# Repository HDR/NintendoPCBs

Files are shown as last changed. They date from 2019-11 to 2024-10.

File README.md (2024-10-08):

# [Make sure you read the License before downloading anything!](https://github.com/HDR/NintendoPCBs/blob/master/LICENSE)

# Please note that these boards can only be used to fix broken games, they can not be used for piracy/bootleg games

**All boards should be ordered in 0.8mm thickness with ENIG, Do not order in 1.6mm thickness or HASL!**

**AGB-E02-20:**

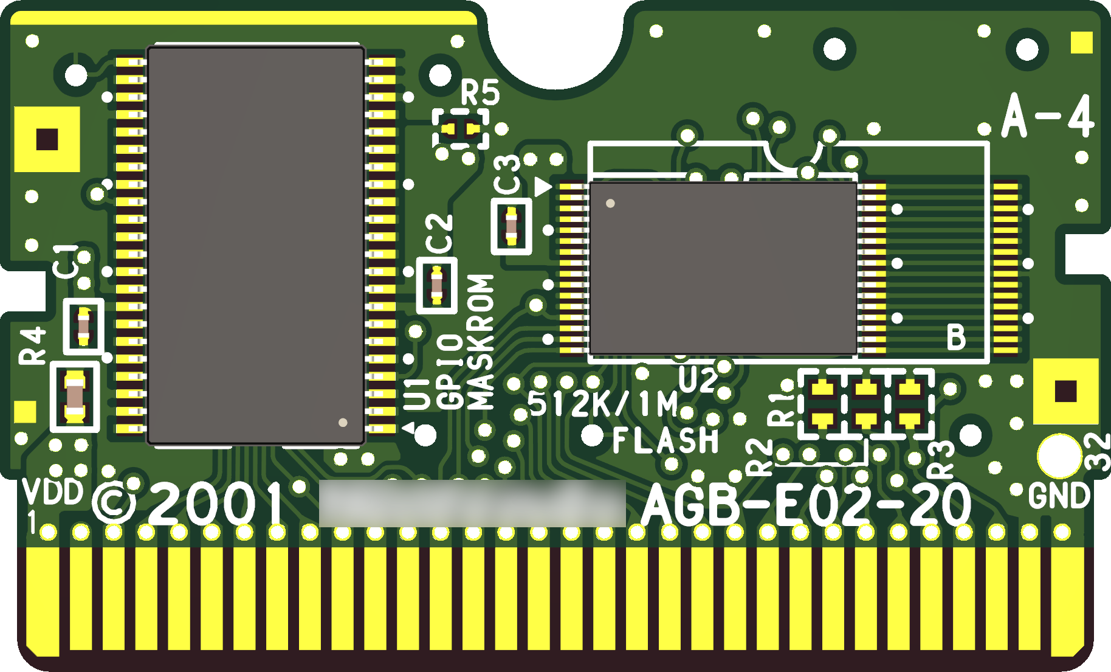
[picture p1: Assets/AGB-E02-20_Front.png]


**AGB-E05-01:**

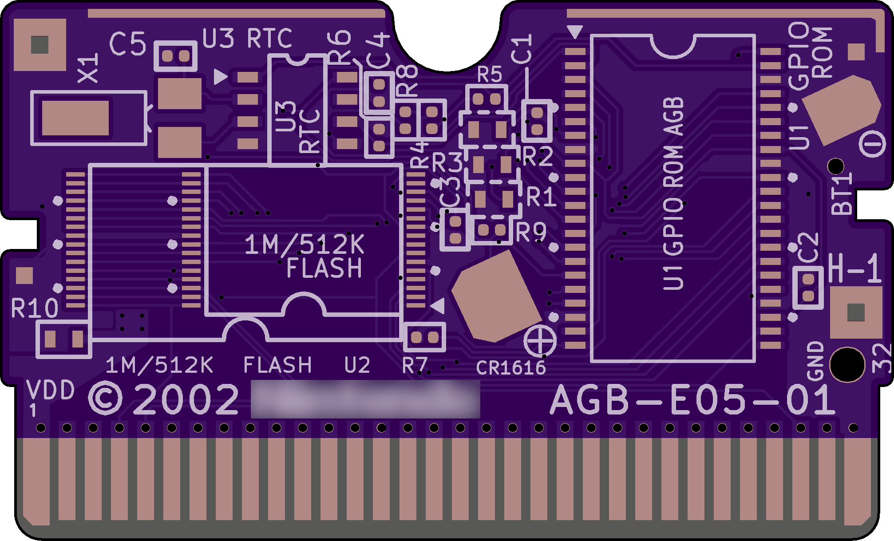
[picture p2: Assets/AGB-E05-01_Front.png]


**DMG-KFDN-01:**

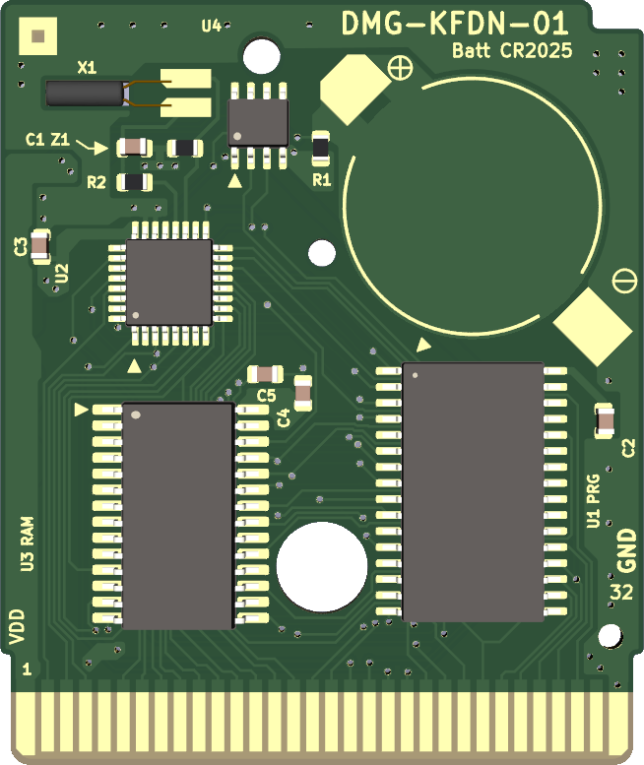
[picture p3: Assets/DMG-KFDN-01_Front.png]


See the [Nintendo Board Scans](https://github.com/HDR/Nintendo_Board_Scans) for more.

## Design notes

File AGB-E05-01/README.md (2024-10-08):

# AGB-E05-01

Intended as a replacement for Games like Emerald

## BOM
| **Designator** | **Part** |
|:---:|:---:|
| C1,C2,C3,C4 | 100nF 0402 |
| C5 | 4pF or 10pF 0402 (depends on the board) |
| R1,R2,R3 | Unpopulated |
| R4,R5,R9 | 10K 0402 |
| R6,R7 | 100K 0402 |
| R8 | 1K 0402 |
| R10 | 2K Resistor 0603 or 1uF Capacitor 0603 (depends on the board) |

### Images


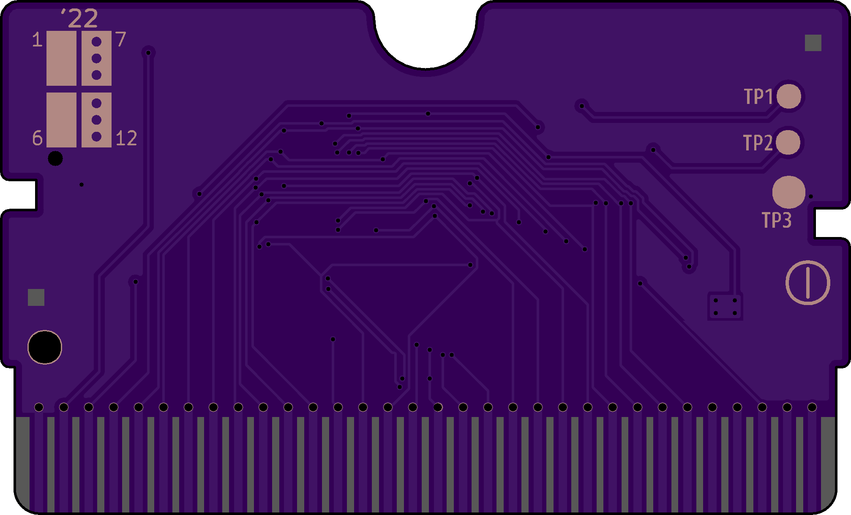
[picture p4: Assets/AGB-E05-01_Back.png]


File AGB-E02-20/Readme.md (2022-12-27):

# AGB-E02-20

Intended as a replacement for Games like Fire Red & Leaf Green

## BOM
| **Designator** | **Part** |
|---|---|
| U1 | MX23L12806-12C (Must to be harvested) |
| U2 | LE26FV10N1TS (Must to be harvested) |
| R1,R2,R3 | Unpopulated |
| R4 | 2.2uF 0603 |
| R5 | Unpopulated |

### Images


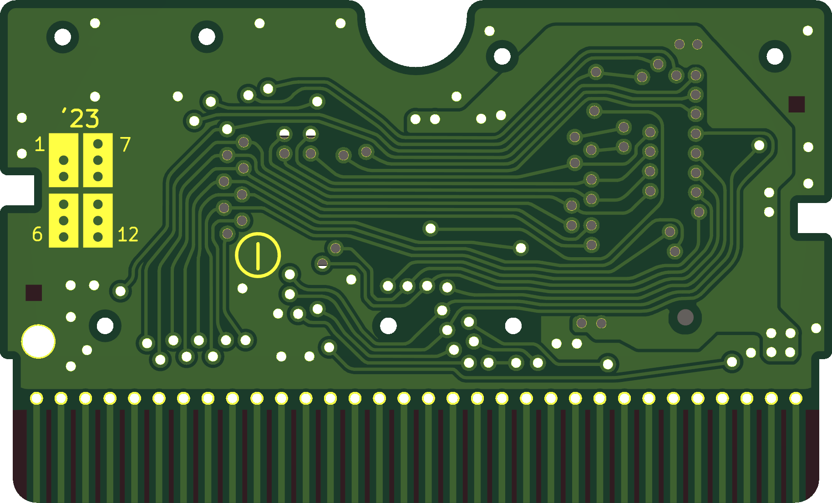
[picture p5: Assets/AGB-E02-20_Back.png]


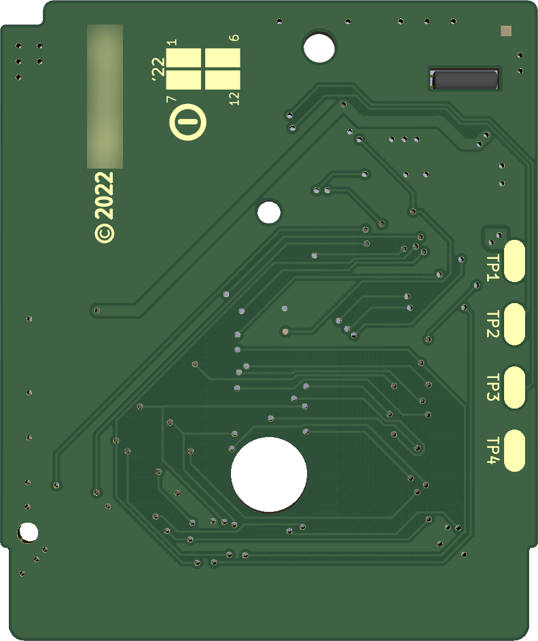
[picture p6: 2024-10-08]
Assets/DMG-KFDN-01_Back.png

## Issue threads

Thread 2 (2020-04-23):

Assembled AGB-E02-20 Board

emuman100, 2020-04-23:
I had the board made with a thickness of .8mm at OSH Park. For the LE26FV10NITS-10 save flash, the pad spacing is just large enough and it had to be very carefully aligned and was a bit difficult to flow solder since the pads were not pretinned, but ENIG plated.

I soldered the save flash, mask ROM, and capacitors of Super Mario Advance 4 and it did not boot. The mask ROM is AX4E-0. Have you tested this design?

HDR, 2020-04-23:
Yep, works as it should.

emuman100, 2020-04-23:
Ok, maybe something happened to this masked ROM. It was a working cartridge, then just stopped working. Usually the masked ROMs are pretty reliable. I'll just have to try with another donor cartridge. Picture attached.
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

emuman100, 2020-04-23:
It won't even read in my insidegadgets programmer. I believe it is the mask ROM.

Closed 2020-04-23.

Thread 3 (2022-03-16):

how to build Dookie ?

hpx1984, 2022-03-16:
Hi Sir HDR

The Ique dookie project is the clones of ique card,right?

i had download Dookie Gerber and Sch but can't open it by CAM350 and Protel99, what PC tool can open it?

the process how to clones ique card in my understand,am i right?
1.dump original NAND from original ique card
2.build Dookie PCBA
3. upload original NAND file to Dookie PCBA

hpx1984, 2022-03-16:
CAM350 can open AGB-E05-01 but Dookie gerber showed as below
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

hpx1984, 2022-03-17:
hi HDR
thanks your replayed

i used CAM350 for open DOOKIE gerber always got error as this or just sew the "Drl" layer
i thinking about for rebuild a ique card for lager memory for install all 14 ique player games in one ique card
and i think DOOKIE project is what i want when i saw this project , i like to try to build it
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

HDR, 2022-03-17:
Your software is broken, you need to upload the gerber to a fab.

hpx1984, 2022-04-02:
Dear MrHDR

i got ique memory card DOOKIE PCB now
and i try for soldering a nand chip and cap on it but i can't programmed nand bin file on it by used ique player hot swap memory card and use ique_diag tool
is it mean need nand programmer for read nand file from original memory card's nand chip then programming nand file to new nand chip by programmer?

sorry for trouble you and many thanks your kindly help

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

HDR, 2022-04-02:
Not sure, i haven't tried using them myself, i just cloned the board.

hpx1984, 2022-04-02:
okay ,let me try myself , many thanks your replied Mr HDR
thank you very much

Closed 2022-03-16.

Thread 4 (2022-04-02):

DMG-KFDN-01 - C4, C5 missing connection to ground.

mkarr, 2022-04-02:
Hi,

It appears that in both the schematic and pcb for the DMG-KFDN-01 project, C4 and C5 are connected together, but that connecting net is not connected to ground.

Looking over the PCB pictures here:

https://gbhwdb.gekkio.fi/cartridges/DMG-APAU-0/mattcurrie-1.html

It appears that the ground connection is there, similar MBC3 boards appear to have the same connections for the SRAM.

Thanks,

Mike

HDR, 2022-04-03:
Whoops, when i originally made some of those i was kind of a newbie when it came to pcb's, i just pushed d1a9a5f which should fix this.

Closed 2022-04-03.

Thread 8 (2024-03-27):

Question - Is there a reason some pads are many pads connected to each other?

sabogalc, 2024-03-27:
In this example, I am looking at the pads of `U1` on the `AGB-E02-20` PCB. I am wondering if there is any particular reason that the pads are all three pads strung together instead of one pad. I am looking to submit a PR that corrects this, but before I do so I wanted to check if this was the intended design.
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

HDR, 2024-03-27:
This is intentional, please look at an original board or the 3d view.

Closed 2024-03-27.

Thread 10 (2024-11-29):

AGB-E02-20 missing materials for C1-C3

andreevgy, 2024-11-29:
Hello!

I am kinda new to hobby electronics and trying to fix AGB-E02-20 that I bought secondhand. I successfully transferred chips and elements that I had on previous board, but from photos online it seems like I have С1-С3 missing.

In the BOM of AGB-E02-20 there is no C1-C3. Maybe they shouldn't be here and I just screwed my cartridge, but I see all other boards mention it. Will appreciate any help and thank you for the designs!

HDR, 2024-11-29:
C1-C3 are 0.1uF (100nF) 0402 capacitors, i've updated the BOM to reflect this

Closed 2024-11-29.

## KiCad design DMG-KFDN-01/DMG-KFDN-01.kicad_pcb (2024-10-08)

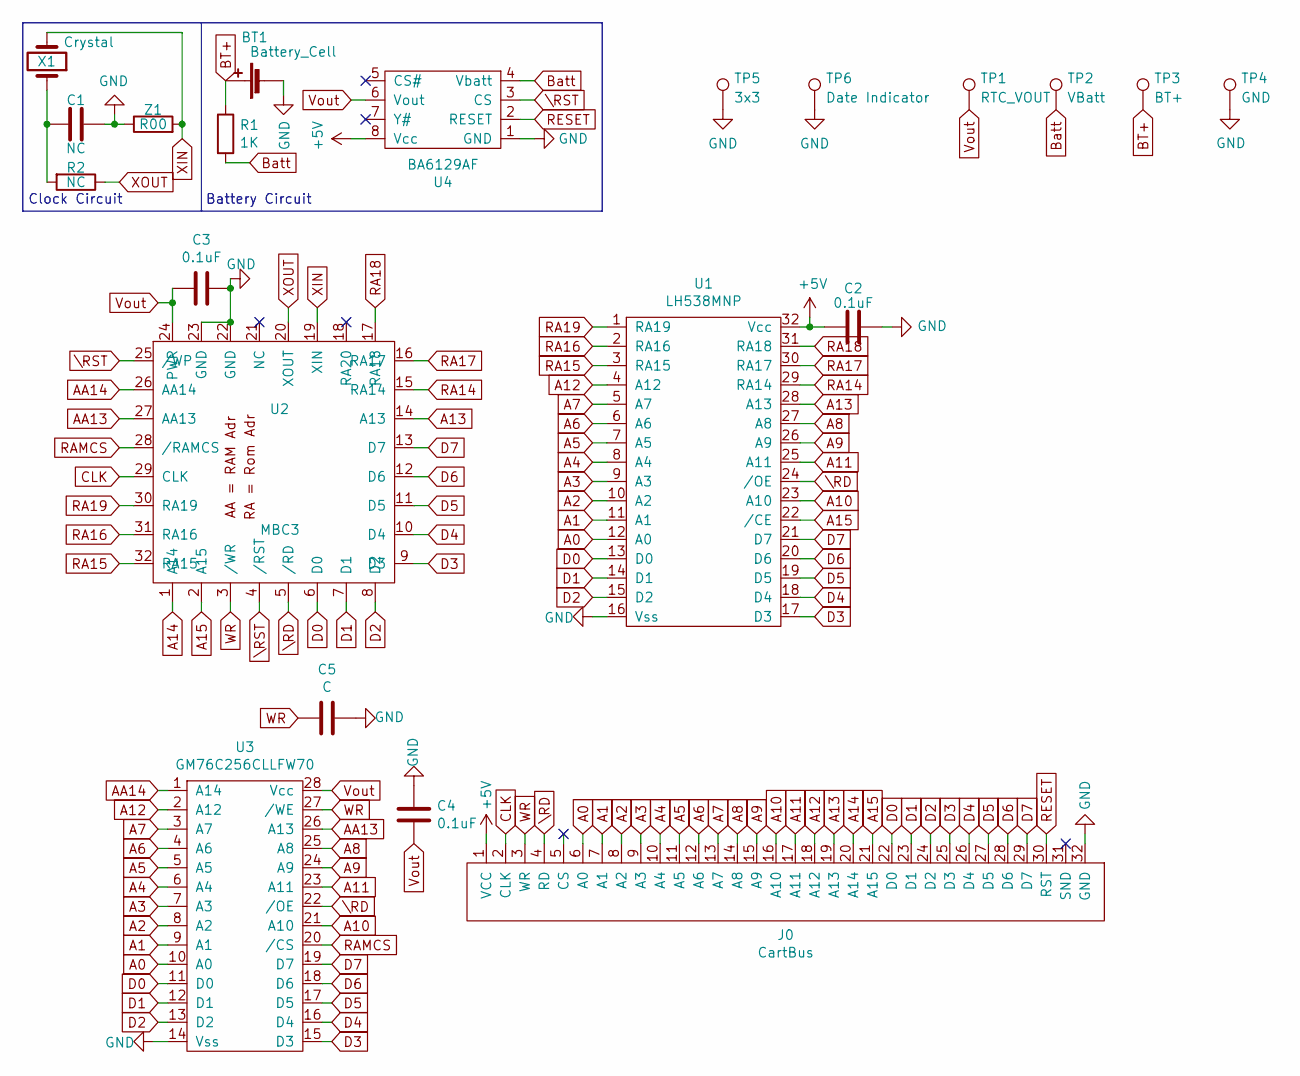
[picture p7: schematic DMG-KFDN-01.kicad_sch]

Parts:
BT1: Battery_Cell; CR2025_Tabbed
C1: NC; C_0805_2012Metric
C2, C3, C4: 0.1uF; C_0805_2012Metric
C5: C; C_0805_2012Metric
J0: CartBus; GB_Cartridge_Front_Only
R1: 1K; R_0805_2012Metric
R2: NC; R_0805_2012Metric
TP1: RTC_VOUT; GameBoy_Testpoint
TP2: VBatt; GameBoy_Testpoint
TP3: BT+; GameBoy_Testpoint
TP4: GND; GameBoy_Testpoint
TP5: 3x3; 3x3mm_Pad
TP6: Date Indicator; 12 December
U1: LH538MNP; SSOP-32_11.305x20.495mm_P1.27mm
U2: MBC3; LQFP-32_7x7mm_P0.8mm
U3: GM76C256CLLFW70; SOIC-28W_7.5x17.9mm_P1.27mm
U4: BA6129AF; SOIC-8_3.9x4.9mm_P1.27mm
X1: Crystal; Resonator_SMD_muRata_CDSCB-2pin_4.5x2.0mm_HandSoldering
Z1: R00; R_0805_2012Metric

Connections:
+5V: C2.1, J0.1 (VCC), U1.32 (Vcc), U4.8 (Vcc)
A0: J0.6 (A0), U1.12 (A0), U3.10 (A0)
A1: J0.7 (A1), U1.11 (A1), U3.9 (A1)
A2: J0.8 (A2), U1.10 (A2), U3.8 (A2)
A3: J0.9 (A3), U1.9 (A3), U3.7 (A3)
A4: J0.10 (A4), U1.8 (A4), U3.6 (A4)
A5: J0.11 (A5), U1.7 (A5), U3.5 (A5)
A6: J0.12 (A6), U1.6 (A6), U3.4 (A6)
A7: J0.13 (A7), U1.5 (A7), U3.3 (A7)
A8: J0.14 (A8), U1.27 (A8), U3.25 (A8)
A9: J0.15 (A9), U1.26 (A9), U3.24 (A9)
A10: J0.16 (A10), U1.23 (A10), U3.21 (A10)
A11: J0.17 (A11), U1.25 (A11), U3.23 (A11)
A12: J0.18 (A12), U1.4 (A12), U3.2 (A12)
A13: J0.19 (A13), U1.28 (A13), U2.14 (A13)
A14: J0.20 (A14), U2.1 (A14)
A15: J0.21 (A15), U1.22 (/CE), U2.2 (A15)
AA13: U2.27 (AA13), U3.26 (A13)
AA14: U2.26 (AA14), U3.1 (A14)
BT+: BT1.1 (+), R1.1, TP3.1; also elsewhere on the board
Batt: R1.2, TP2.1, U4.4 (Vbatt)
CLK: J0.2 (CLK~), U2.29 (CLK)
D0: J0.22 (D0), U1.13 (D0), U2.6 (D0), U3.11 (D0)
D1: J0.23 (D1), U1.14 (D1), U2.7 (D1), U3.12 (D1)
D2: J0.24 (D2), U1.15 (D2), U2.8 (D2), U3.13 (D2)
D3: J0.25 (D3), U1.17 (D3), U2.9 (D3), U3.15 (D3)
D4: J0.26 (D4), U1.18 (D4), U2.10 (D4), U3.16 (D4)
D5: J0.27 (D5), U1.19 (D5), U2.11 (D5), U3.17 (D5)
D6: J0.28 (D6), U1.20 (D6), U2.12 (D6), U3.18 (D6)
D7: J0.29 (D7), U1.21 (D7), U2.13 (D7), U3.19 (D7)
GND: BT1.2 (-), C1.2, C2.2, C3.2, C4.1, C5.1, J0.32 (GND), TP4.1, TP5.1, TP6.1, U1.16 (Vss), U2.22 (GND), U2.23 (GND), U3.14 (Vss), U4.1 (GND), Z1.1; also elsewhere on the board
unnamed: C1.1, R2.2, X1.1
RA14: U1.29 (RA14), U2.15 (RA14)
RA15: U1.3 (RA15), U2.32 (RA15)
RA16: U1.2 (RA16), U2.31 (RA16)
RA17: U1.30 (RA17), U2.16 (RA17)
RA18: U1.31 (RA18), U2.17 (RA18)
RA19: U1.1 (RA19), U2.30 (RA19)
RAMCS: U2.28 (/RAMCS), U3.20 (/CS)
RESET: J0.30 (RST), U4.2 (RESET)
Vout: C3.1, C4.2, TP1.1, U2.24 (PWR), U3.28 (Vcc), U4.6 (Vout)
WR: C5.2, J0.3 (WR), U2.3 (/WR), U3.27 (/WE)
XIN: U2.19 (XIN), X1.2, Z1.2
XOUT: R2.1, U2.20 (XOUT)
\RD: J0.4 (RD), U1.24 (/OE), U2.5 (/RD), U3.22 (/OE)
\RST: U2.4 (/RST), U2.25 (/WP), U4.3 (CS)

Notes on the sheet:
Battery Circuit
Clock Circuit

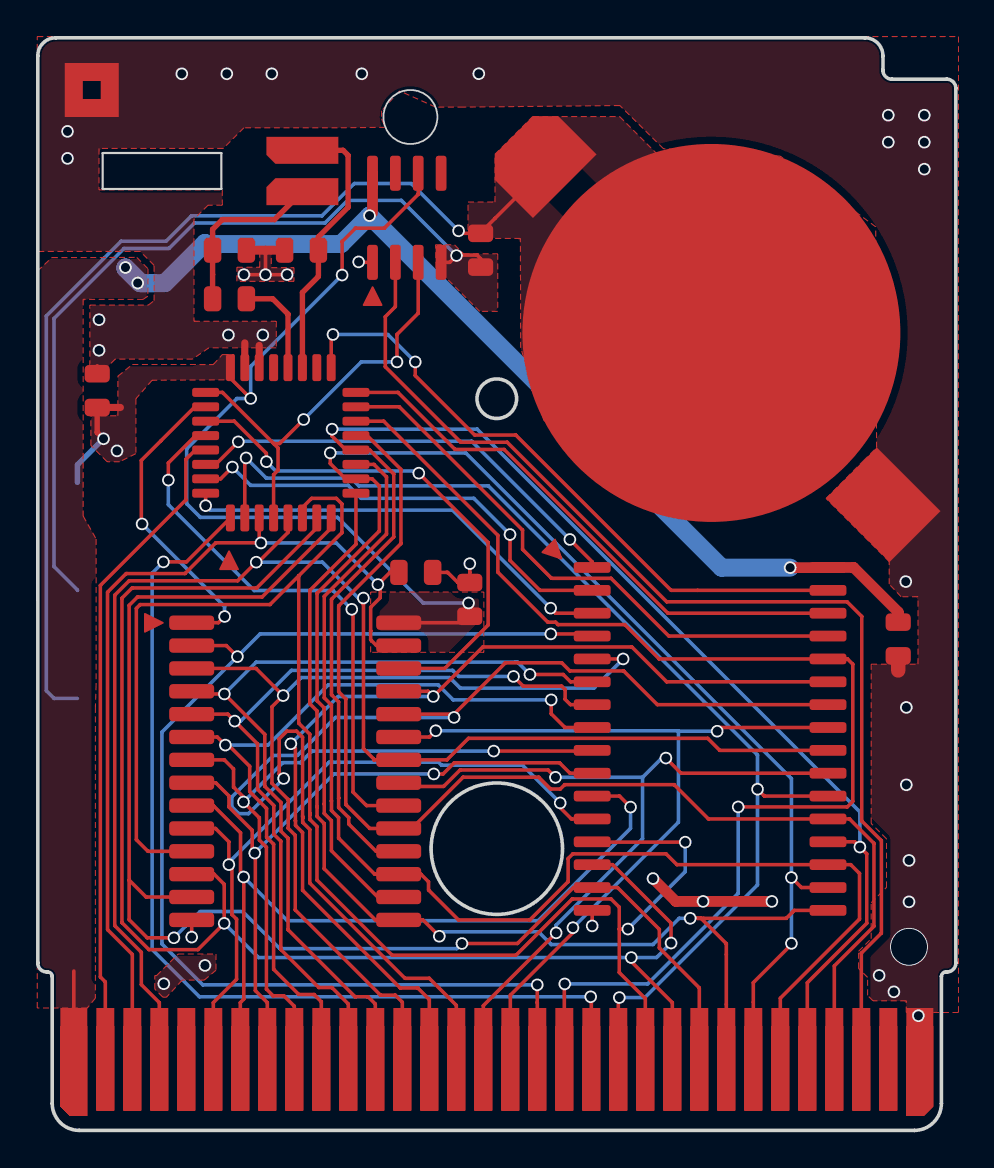
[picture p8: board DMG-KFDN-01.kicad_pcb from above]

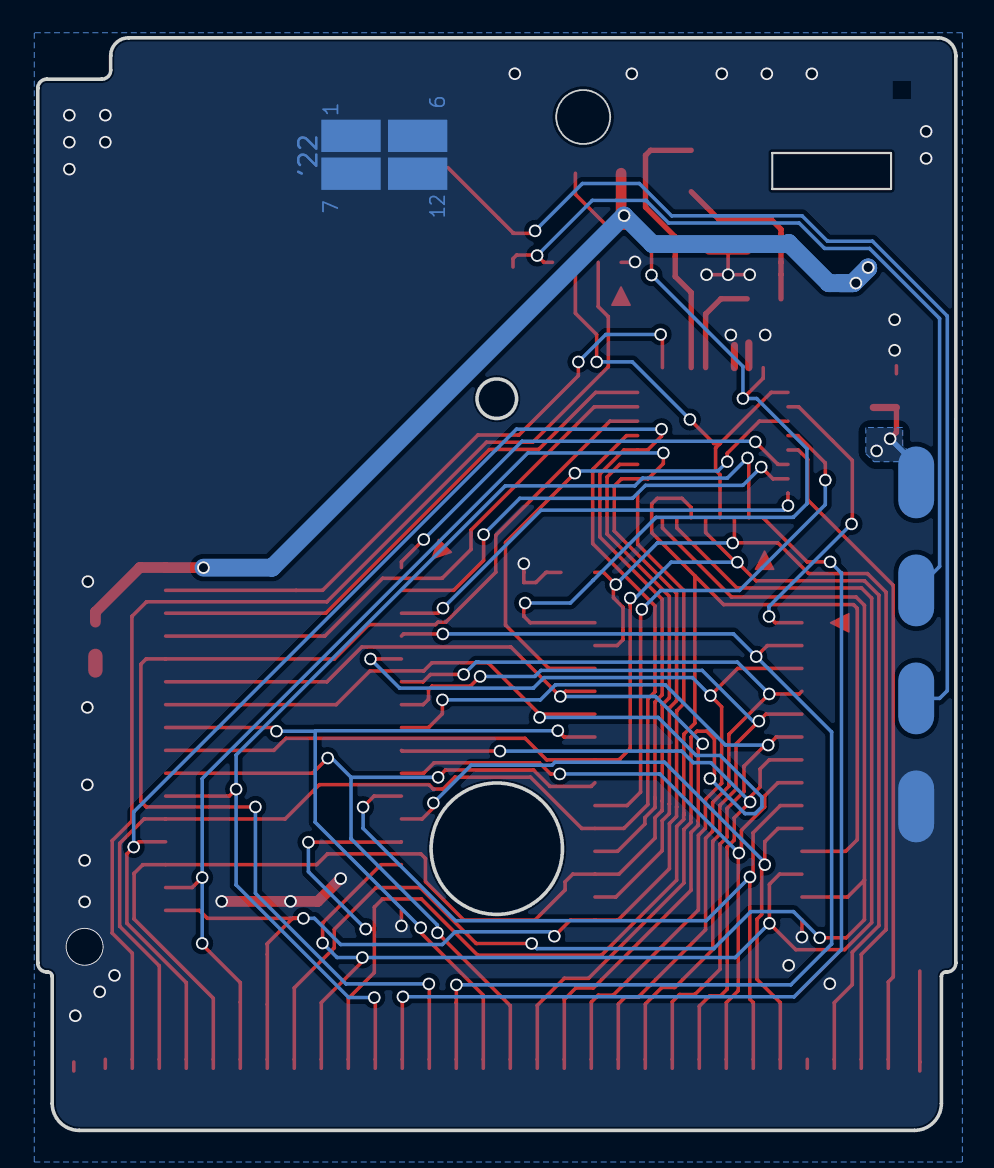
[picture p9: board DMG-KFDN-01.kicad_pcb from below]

Board: 2 copper layers, 51.0 x 60.7 mm, 21 parts (5 on the bottom side), 46 nets.

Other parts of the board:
Batt CR2025: Battery_Cell; CR2025_Tabbed

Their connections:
BT+: Batt CR2025.1 (+); also elsewhere on the board
GND: Batt CR2025.2 (-); also elsewhere on the board

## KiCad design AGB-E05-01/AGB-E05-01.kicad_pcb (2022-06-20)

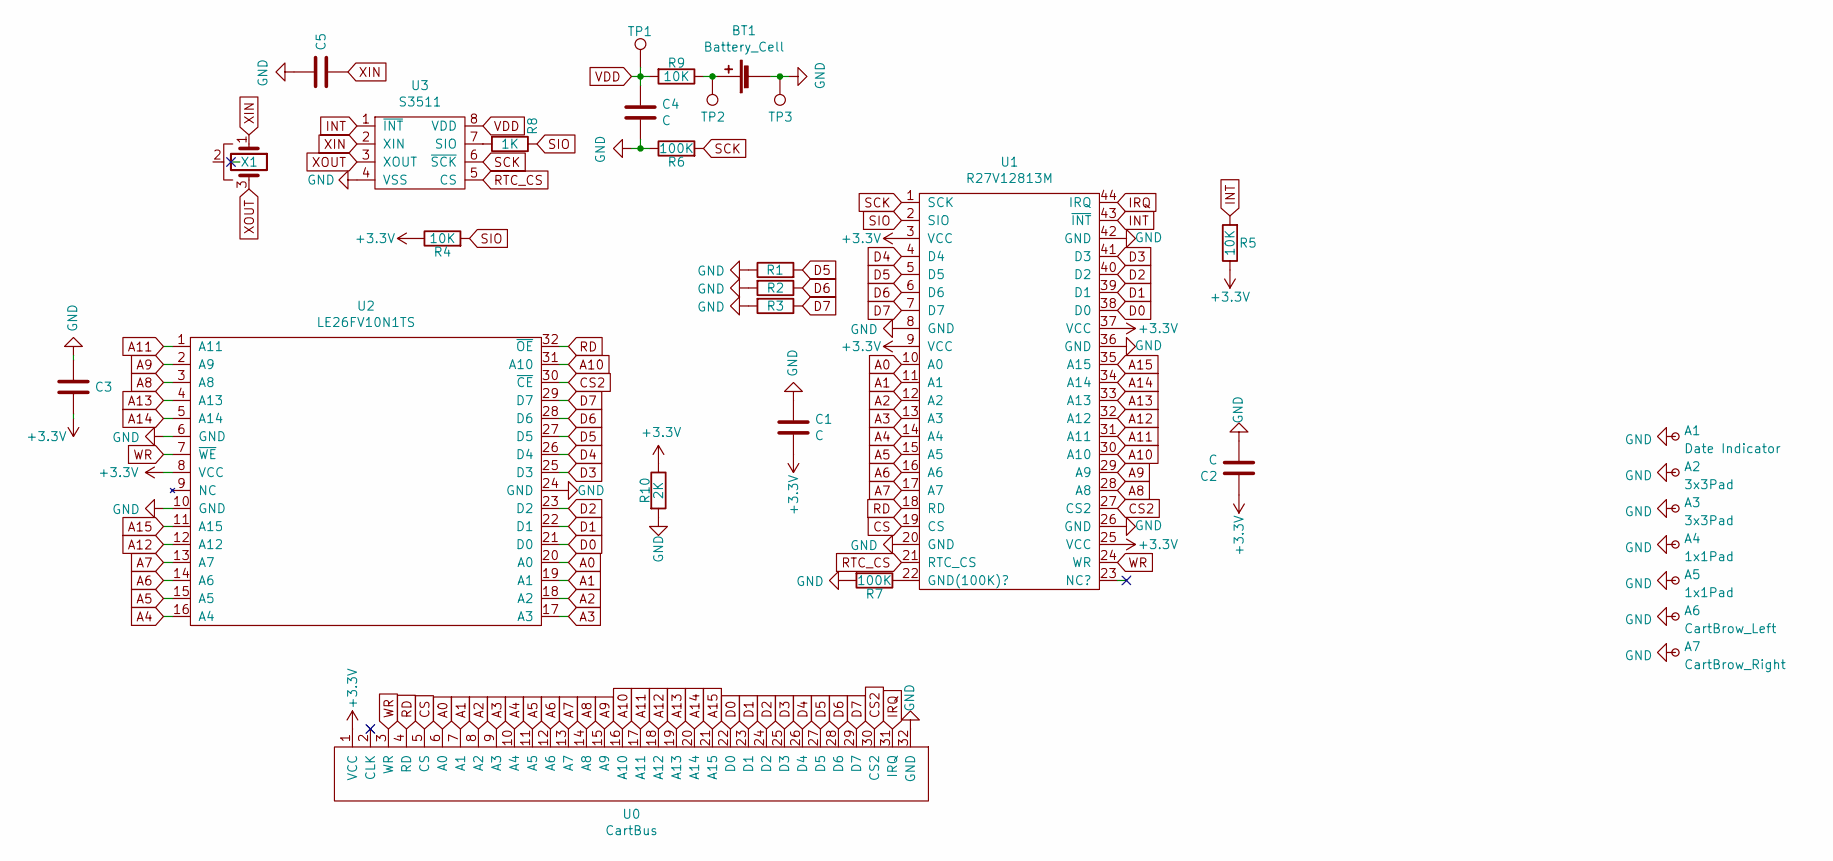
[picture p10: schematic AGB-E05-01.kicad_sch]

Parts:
A1: Date Indicator; 05 May
A2, A3: 3x3Pad; 3x3mm_Pad
A4, A5: 1x1Pad; 1x1mm_Pad
A6: CartBrow_Left; AGB-Cartbrow_Left
A7: CartBrow_Right; AGB-Cartbrow_Right
BT1: Battery_Cell; AGB-CR1616
C1, C2, C3, C4, C5: C; AGB-C_0402
R1, R2, R3: NC; AGB-R-0603_OPT
R4, R5, R9: 10K; AGB-R_0402
R6, R7: 100K; AGB-R_0402
R8: 1K; AGB-R_0402
R10: 2K; AGB-R-0603
TP1, TP2: TestPoint; AGB-Testpoint
TP3: TestPoint; AGB-Testpoint_Ground
U0: CartBus; AGB_Cartridge
U1: R27V12813M; AGB-TSOP-II-44_10.16x18.41mm_P0.8mm
U2: LE26FV10N1TS; AGB-TSOP-I-32
U3: S3511; AGB-SSOP8
X1: Crystal_GND2; AGB-Crystal

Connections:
+3V3: C1.1, C2.2, C3.1, R4.1, R5.1, R10.1, U0.1 (VCC), U1.3 (VCC), U1.9 (VCC), U1.25 (VCC), U1.37 (VCC), U2.8 (VCC)
A0: U0.6 (A0), U1.10 (A0), U2.20 (A0)
A1: U0.7 (A1), U1.11 (A1), U2.19 (A1)
A2: U0.8 (A2), U1.12 (A2), U2.18 (A2)
A3: U0.9 (A3), U1.13 (A3), U2.17 (A3)
A4: U0.10 (A4), U1.14 (A4), U2.16 (A4)
A5: U0.11 (A5), U1.15 (A5), U2.15 (A5)
A6: U0.12 (A6), U1.16 (A6), U2.14 (A6)
A7: U0.13 (A7), U1.17 (A7), U2.13 (A7)
A8: U0.14 (A8), U1.28 (A8), U2.3 (A8)
A9: U0.15 (A9), U1.29 (A9), U2.2 (A9)
A10: U0.16 (A10), U1.30 (A10), U2.31 (A10)
A11: U0.17 (A11), U1.31 (A11), U2.1 (A11)
A12: U0.18 (A12), U1.32 (A12), U2.12 (A12)
A13: U0.19 (A13), U1.33 (A13), U2.4 (A13)
A14: U0.20 (A14), U1.34 (A14), U2.5 (A14)
A15: U0.21 (A15), U1.35 (A15), U2.11 (A15)
CS: U0.5 (CS), U1.19 (CS)
CS2: U0.30 (CS2), U1.27 (CS2), U2.30 (~CE)
D0: U0.22 (D0), U1.38 (D0), U2.21 (D0)
D1: U0.23 (D1), U1.39 (D1), U2.22 (D1)
D2: U0.24 (D2), U1.40 (D2), U2.23 (D2)
D3: U0.25 (D3), U1.41 (D3), U2.25 (D3)
D4: U0.26 (D4), U1.4 (D4), U2.26 (D4)
D5: R1.2, U0.27 (D5), U1.5 (D5), U2.27 (D5)
D6: R2.1, U0.28 (D6), U1.6 (D6), U2.28 (D6)
D7: R3.1, U0.29 (D7), U1.7 (D7), U2.29 (D7)
GND: A1.1, A2.1, A3.1, A4.1, A5.1, A6.1, A7.1, BT1.2 (-), C1.2, C2.1, C3.2, C4.1, C5.1, R1.1, R2.2, R3.2, R6.1, R7.2, R10.2, TP3.1, U0.32 (GND), U1.8 (GND), U1.20 (GND), U1.26 (GND), U1.36 (GND), U1.42 (GND), U2.6 (GND), U2.10 (GND), U2.24 (GND), U3.4 (VSS); also elsewhere on the board
INT: R5.2, U1.43 (~INT), U3.1 (~INT)
IRQ: U0.31 (IRQ), U1.44 (IRQ)
unnamed: BT1.1 (+), R9.1, TP2.1
unnamed: R7.1, U1.22 (GND(100K)?)
unnamed: R8.2, U3.7 (SIO)
RD: U0.4 (RD), U1.18 (RD), U2.32 (~OE)
RTC_CS: U1.21 (RTC_CS), U3.5 (CS)
SCK: R6.2, U1.1 (SCK), U3.6 (~SCK)
SIO: R4.2, R8.1, U1.2 (SIO)
VDD: C4.2, R9.2, TP1.1, U3.8 (VDD)
WR: U0.3 (WR), U1.24 (WR), U2.7 (~WE)
XIN: C5.2, U3.2 (XIN), X1.1
XOUT: U3.3 (XOUT), X1.3

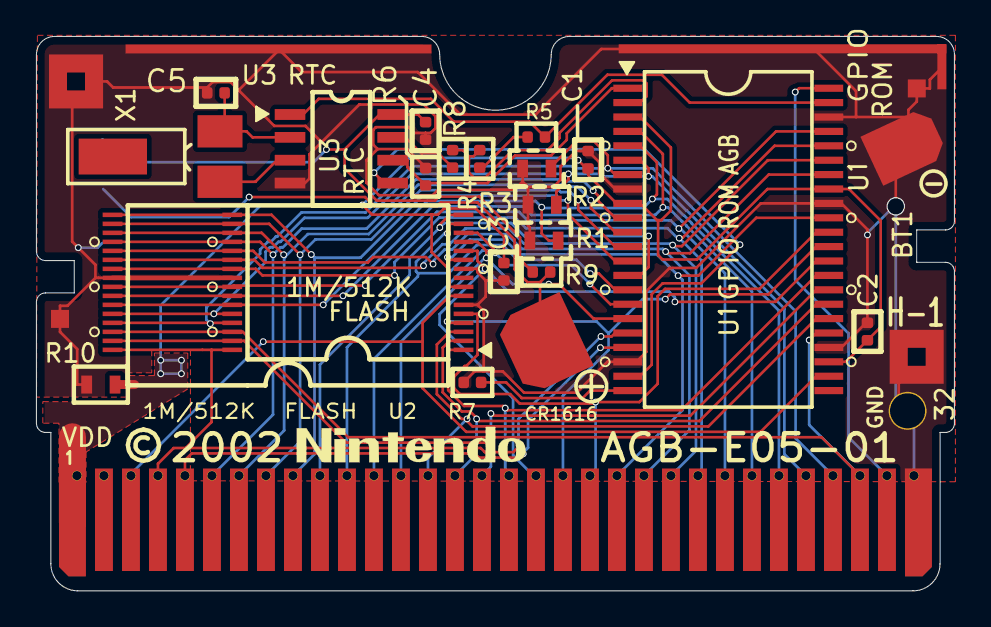
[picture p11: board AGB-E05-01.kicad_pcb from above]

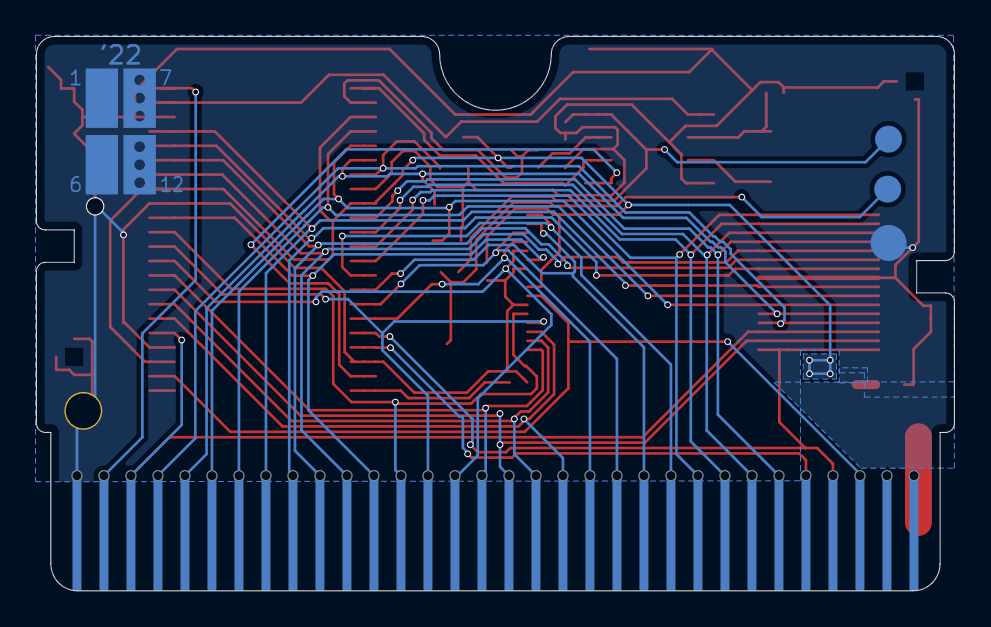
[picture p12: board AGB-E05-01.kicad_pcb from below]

Board: 2 copper layers, 51.0 x 30.8 mm, 36 parts (7 on the bottom side), 41 nets.

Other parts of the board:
G1: Nintendo Logo; Nintendo-GBA-Logo
PlatedHole1: MountingHole; TestPoint_Plated_Hole_D2.0mm
kibuzzard-62A1ACD3: G***; kibuzzard-62A1ACD3
kibuzzard-62A1AD16: G***; kibuzzard-62A1AD16
kibuzzard-62A1AD21: G***; kibuzzard-62A1AD21

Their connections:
GND: PlatedHole1.1; also elsewhere on the board

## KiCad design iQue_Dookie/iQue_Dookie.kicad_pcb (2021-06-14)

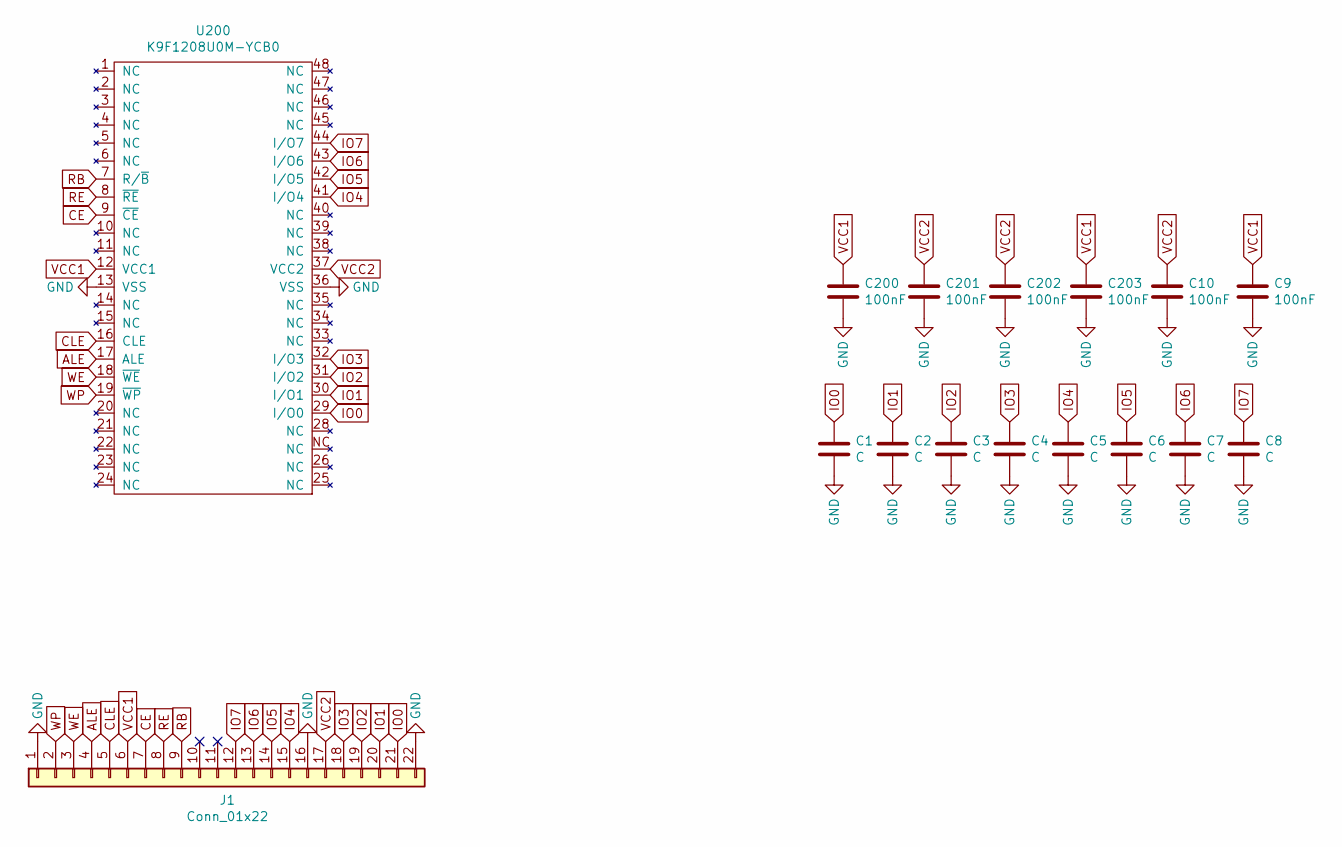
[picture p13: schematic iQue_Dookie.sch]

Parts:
C1, C2, C3, C4, C5, C6, C7, C8: C; C_0402_1005Metric
C9, C10, C200, C201, C202, C203: 100nF; C_0402_1005Metric
J1: Conn_01x22; iQue_Dookie_CartBus
U200: K9F1208U0M-YCB0; TSOP-I-48_18.4x12mm_P0.5mm

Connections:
ALE: J1.4, U200.17 (ALE); also elsewhere on the board
CE: J1.7, U200.9 (~CE); also elsewhere on the board
CLE: J1.5, U200.16 (CLE); also elsewhere on the board
GND: C1.2, C2.2, C3.2, C4.2, C5.2, C6.2, C7.2, C8.2, C9.2, C10.2, C200.2, C201.2, C202.2, C203.2, J1.1, J1.16, J1.22, U200.13 (VSS), U200.36 (VSS); also elsewhere on the board
IO0: C1.1, J1.21, U200.29 (I/O0); also elsewhere on the board
IO1: C2.1, J1.20, U200.30 (I/O1); also elsewhere on the board
IO2: C3.1, J1.19, U200.31 (I/O2); also elsewhere on the board
IO3: C4.1, J1.18, U200.32 (I/O3); also elsewhere on the board
IO4: C5.1, J1.15, U200.41 (I/O4); also elsewhere on the board
IO5: C6.1, J1.14, U200.42 (I/O5); also elsewhere on the board
IO6: C7.1, J1.13, U200.43 (I/O6); also elsewhere on the board
IO7: C8.1, J1.12, U200.44 (I/O7); also elsewhere on the board
RB: J1.9, U200.7 (R/~B); also elsewhere on the board
RE: J1.8, U200.8 (~RE); also elsewhere on the board
VCC1: C9.1, C200.1, C203.1, J1.6, U200.12 (VCC1); also elsewhere on the board
VCC2: C10.1, C201.1, C202.1, J1.17, U200.37 (VCC2); also elsewhere on the board
WE: J1.3, U200.18 (~WE); also elsewhere on the board
WP: J1.2, U200.19 (~WP); also elsewhere on the board

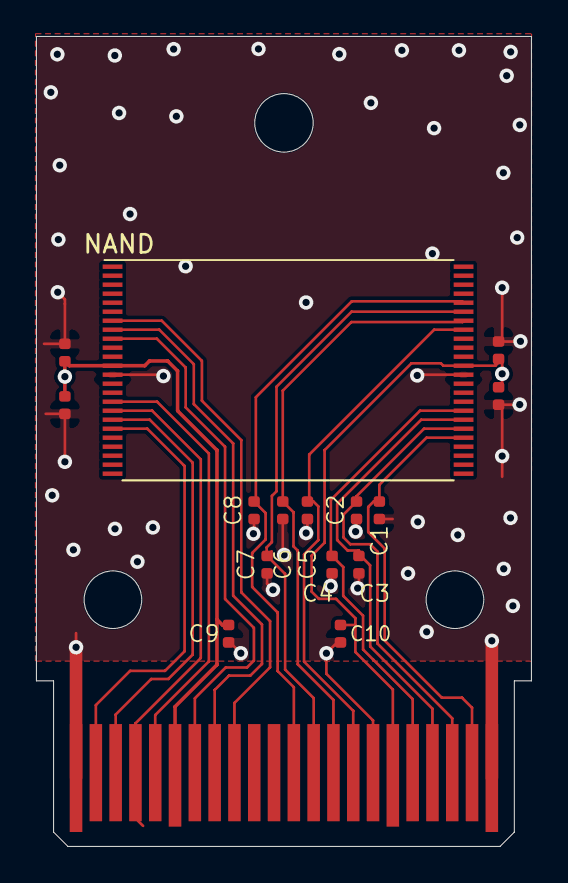
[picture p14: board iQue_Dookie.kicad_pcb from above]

Board: 2 copper layers, 27.5 x 45.0 mm, 16 parts (0 on the bottom side), 18 nets.

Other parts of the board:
NAND: K9F1208U0M-YCB0; TSOP-I-48_18.4x12mm_P0.5mm

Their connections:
ALE: NAND.17; also elsewhere on the board
CE: NAND.9; also elsewhere on the board
CLE: NAND.16; also elsewhere on the board
GND: NAND.13, NAND.36; also elsewhere on the board
IO0: NAND.29; also elsewhere on the board
IO1: NAND.30; also elsewhere on the board
IO2: NAND.31; also elsewhere on the board
IO3: NAND.32; also elsewhere on the board
IO4: NAND.41; also elsewhere on the board
IO5: NAND.42; also elsewhere on the board
IO6: NAND.43; also elsewhere on the board
IO7: NAND.44; also elsewhere on the board
RB: NAND.7; also elsewhere on the board
RE: NAND.8; also elsewhere on the board
VCC1: NAND.12; also elsewhere on the board
VCC2: NAND.37; also elsewhere on the board
WE: NAND.18; also elsewhere on the board
WP: NAND.19; also elsewhere on the board

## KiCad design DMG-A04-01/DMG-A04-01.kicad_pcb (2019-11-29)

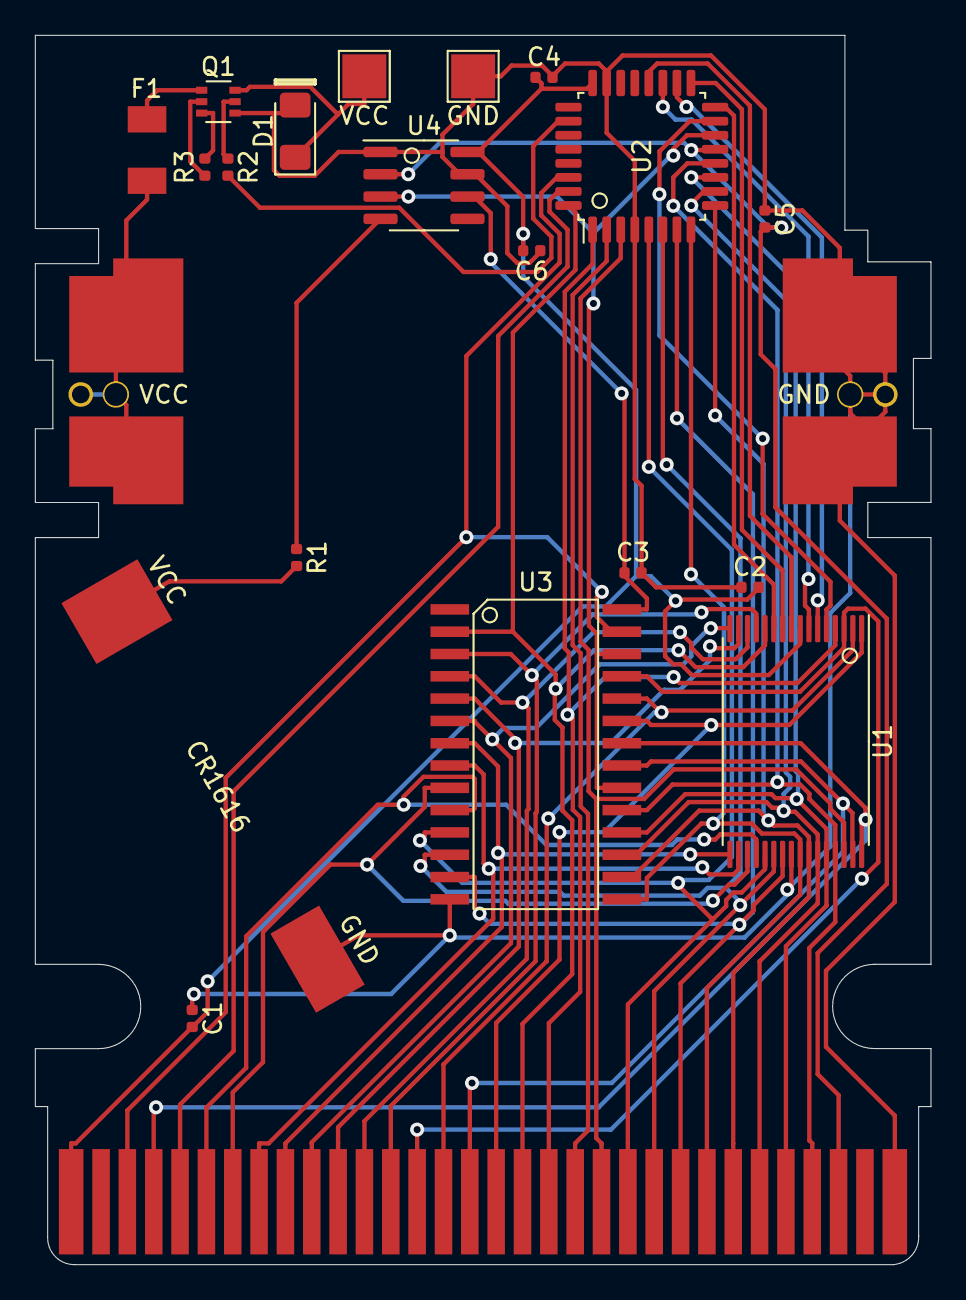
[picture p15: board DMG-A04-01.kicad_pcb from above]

Board: 2 copper layers, 51.0 x 70.0 mm, 22 parts (0 on the bottom side), 47 nets.

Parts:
C1, C2, C3, C4, C6: C; C_0402_1005Metric
C5: NC; C_0402_1005Metric
CR1616: CR1616; CR1616-DMG
D1: D; D_1206_3216Metric_Pad1.42x1.75mm_HandSolder
F1: 10; DMG-A04-01_Fuse
GND: AAA GND; DMG-A04-01_BAT2-Negative
GND#2: Motor GND; TestPoint_Pad_2.5x2.5mm
Q1: PNP Transistor; DMG-A04-01-Q1
R1: 10K; R_0402_1005Metric
R2: 30K; R_0402_1005Metric
R3: 390; R_0402_1005Metric
U0: CartBus; GBBus
U1: MX23C8006-12; TSOP-I-32_11.8x8mm_P0.5mm
U2: MBC5; LQFP-32_7x7mm_P0.8mm
U3: HY6264A
U4: MM1134A; SOIC-8_3.9x4.9mm_P1.27mm
VCC: AAA Positive; DMG-A04-01_BAT2-Positive
VCC#2: Motor VCC; TestPoint_Pad_2.5x2.5mm

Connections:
+5V: C1.2, C2.2, C4.1, C6.2, U0.1, U1.8, U2.24, U4.8
A0: U0.6, U1.20, U3.10
A1: U0.7, U1.19, U3.9
A2: U0.8, U1.18, U3.8
A3: U0.9, U1.17, U3.7
A4: U0.10, U1.16, U3.6
A5: U0.11, U1.15, U3.5
A6: U0.12, U1.14, U3.4
A7: U0.13, U1.13, U3.3
A8: U0.14, U1.3, U3.25
A9: U0.15, U1.2, U3.24
A10: U0.16, U1.31, U3.21
A11: U0.17, U1.1, U3.23
A12: U0.18, U1.12, U2.32, U3.2
A13: U0.19, U1.4, U2.1
A14: U0.20, U2.2
A15: U0.21, U1.30, U2.3
AA16: R2.2, U2.26
CS: U0.5, U2.31
D0: U0.22, U1.21, U2.5, U3.11
D1: U0.23, U1.22, U2.6, U3.12
D2: U0.24, U1.23, U2.7, U3.13
D3: U0.25, U1.25, U2.8, U3.15
D4: U0.26, U1.26, U2.9, U3.16
D5: U0.27, U1.27, U2.10, U3.17
D6: U0.28, U1.28, U2.11, U3.18
D7: U0.29, U1.29, U2.12, U3.19
GND: C1.1, C2.1, C3.2, C4.2, C5.1, C6.1, CR1616.2, D1.2, GND.1, GND#2.1, Q1.4, U0.32, U1.24, U2.4, U2.23, U3.14, U4.1, U4.7
unnamed: CR1616.1, R1.2
unnamed: F1.1, VCC.1
unnamed: D1.1, Q1.6, VCC#2.1
unnamed: F1.2, Q1.1
unnamed: Q1.2, R3.1
unnamed: Q1.3, R3.2
unnamed: Q1.5, R2.1
unnamed: R1.1, U4.4
RA14: U1.5, U2.15
RA15: U1.11, U2.16
RA16: U1.10, U2.17
RA17: U1.6, U2.18
RA18: U1.7, U2.19
RA19: U1.9, U2.20
RAMCS: U2.14, U3.20, U3.26, U4.3
RESET: C5.2, U0.30, U2.13, U4.2
RamVcc: C3.1, U3.28, U4.6
WR: U0.3, U2.30, U3.27
\RD: U0.4, U1.32, U3.22

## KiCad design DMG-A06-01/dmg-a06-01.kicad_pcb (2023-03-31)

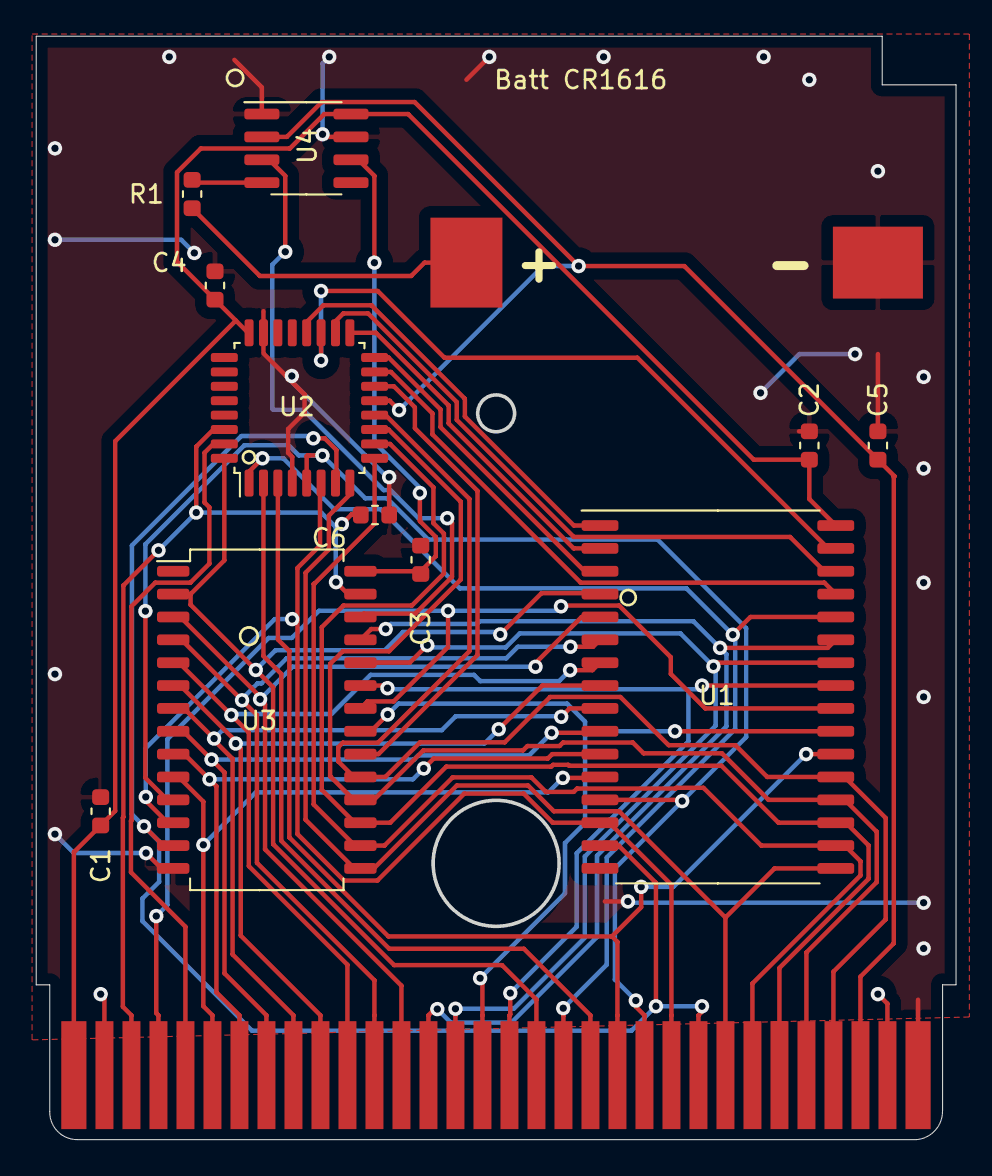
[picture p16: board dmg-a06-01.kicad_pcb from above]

Board: 2 copper layers, 51.1 x 61.3 mm, 13 parts (0 on the bottom side), 41 nets.

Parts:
Batt CR1616: Battery_Cell; CR2025
C1: NC; C_0603_1608Metric
C2, C3, C4, C6: 0.1uF; C_0603_1608Metric
C5: C; C_0603_1608Metric
R1: NC; R_0603_1608Metric
U0: CartBus
U1: LH538MNP; SSOP-32_11.305x20.495mm_P1.27mm
U2: MBC5; LQFP-32_7x7mm_P0.8mm
U3: GM76C256CLLFW70
U4: BA6129AF; SOIC-8_3.9x4.9mm_P1.27mm

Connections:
+5V: C1.1, C2.2, C4.2, U0.1, U1.32, U2.24, U4.8
A0: U0.6, U1.12, U3.10
A1: U0.7, U1.11, U3.9
A2: U0.8, U1.10, U3.8
A3: U0.9, U1.9, U3.7
A4: U0.10, U1.8, U3.6
A5: U0.11, U1.7, U3.5
A6: U0.12, U1.6, U3.4
A7: U0.13, U1.5, U3.3
A8: U0.14, U1.27, U3.25
A9: U0.15, U1.26, U3.24
A10: U0.16, U1.23, U3.21
A11: U0.17, U1.25, U3.23
A12: U0.18, U1.4, U2.32, U3.2
A13: U0.19, U1.28, U2.1
A14: U0.20, U2.2
A15: U0.21, U1.22, U2.3
AA13: U3.26, U4.3
Batt: R1.2, U4.4
D0: U0.22, U1.13, U2.5, U3.11
D1: U0.23, U1.14, U2.6, U3.12
D2: U0.24, U1.15, U2.7, U3.13
D3: U0.25, U1.17, U2.8, U3.15
D4: U0.26, U1.18, U2.9, U3.16
D5: U0.27, U1.19, U2.10, U3.17
D6: U0.28, U1.20, U2.11, U3.18
D7: U0.29, U1.21, U2.12, U3.19
GND: Batt CR1616.2, C1.2, C2.1, C3.2, C4.1, C5.2, C6.2, U0.32, U1.16, U2.4, U2.23, U3.14, U4.1, U4.7
unnamed: Batt CR1616.1, R1.1
unnamed: U0.5, U2.31
RA14: U1.29, U2.15
RA15: U1.3, U2.16
RA16: U1.2, U2.17
RA17: U1.30, U2.18
RAMCS: U2.14, U3.20
RESET: C5.1, U0.30, U2.13, U4.2
Vout: C3.1, U3.28, U4.6
WR: C6.1, U0.3, U2.30, U3.27
XIN: U1.31, U2.19
XOUT: U1.1, U2.20
\RD: U0.4, U1.24, U3.22

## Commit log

2019-10-14 Add Gerber
    [DMG-KFDN-01.kicad_pcb]
2019-10-19 Add AGB-E05-01
    Added AGB-E05-01, this is a board mainly for Pokemon Ruby, Sapphire and
    Emerald
    [AGB-E05-01.kicad_pcb, AGB-E05-01.sch]
2019-10-19 Add gerbers for AGB-E05-01
2019-11-14 Move R7 and R10 up
    [AGB-E05-01.kicad_pcb]
2019-11-14 Move battery pads slightly up
    [AGB-E05-01.kicad_pcb]
2019-11-16 Update AGB-E05-01
    Moved bottom of screwpost cutout down slightly for better alignment,
    moved all components up to make the pcb fit like it should inside the
    original shell
    [AGB-E05-01.kicad_pcb]
2019-11-29 Added DMG-A04-01
    Added DMG-A04-01 (Pokemon Pinball), keep in mind this board is untested
    [AGB-E05-01.kicad_pcb, DMG-A04-01.kicad_pcb, DMG-A04-01.sch]
2019-12-22 Added AGB-E02-20
    AGB-E02-20 supports Fire Red and Leaf Green
    [AGB-E02-20.kicad_pcb, AGB-E02-20.sch]
2020-03-31 Added DMG-A06-01 board
    [dmg-a06-01.kicad_pcb]
2020-03-31 Added .pro and gerber files for DMG-A06-01
2020-08-18 Update AGB-E02-20
    AGB-E02-20 looks much more "OEM" now
    [AGB-E02-20.kicad_pcb, AGB-E02-20.sch]
2020-10-16 Update AGB-E02-20
    AGB-E02-20 is now mostly identical to the original pcb (this was a lot of work)
    [AGB-E02-20.kicad_pcb, AGB-E02-20.sch]
2021-06-14 add the iQue "Dookie"
    [iQue_Dookie.kicad_pcb]
2022-04-03 Fix issues with DMG-KFDN-01 (see #4)
    [DMG-KFDN-01.kicad_pcb, DMG-KFDN-01.kicad_sch, DMG-KFDN-01.sch]
2022-06-20 Updated AGB-E05-01 to look more original
    [AGB-E05-01.kicad_pcb, AGB-E05-01.kicad_sch, AGB-E05-01.sch]
2022-08-21 KDFN -> KFDN (silkscr typo)
    [DMG-KFDN-01.kicad_pcb]
2022-08-22 Updated KFDN gerbers
2023-01-16 Add AGB-E02-20 OpenBoardView file
    [AGB-E02-20.brd]
2023-03-05 Update AGB-E02-20
    1 to 1 traces
    KiCad 7
    [AGB-E02-20.kicad_sch, AGB-E02-20.sch]
2023-03-23 Created version 1.1 of DMG-A06-01 replacement PCB
    [dmg-a06-01.kicad_pcb]
2023-03-31 Update DMG-KFDN-01
    [DMG-KFDN-01.kicad_pcb, DMG-KFDN-01.kicad_sch]
2024-10-08 Remove logos
    [DMG-KFDN-01.kicad_pcb]
2024-10-08 Fix missing traces
2026-01-08 Fix AGB-E05-01 Kicad PCB File
    Fixes missing traces from AGB-E05-01.kicad_pcb
2026-01-08 Update AGB-05-01 Kicad files
    Upgrade to kicad 9.0
